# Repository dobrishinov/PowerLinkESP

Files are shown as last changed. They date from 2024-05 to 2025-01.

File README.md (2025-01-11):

# PowerLinkESP

PowerLinkESP is an advanced firmware designed to enhance Nice-Power bench power supplies with ESP8266 connectivity, providing advanced monitoring and control capabilities.

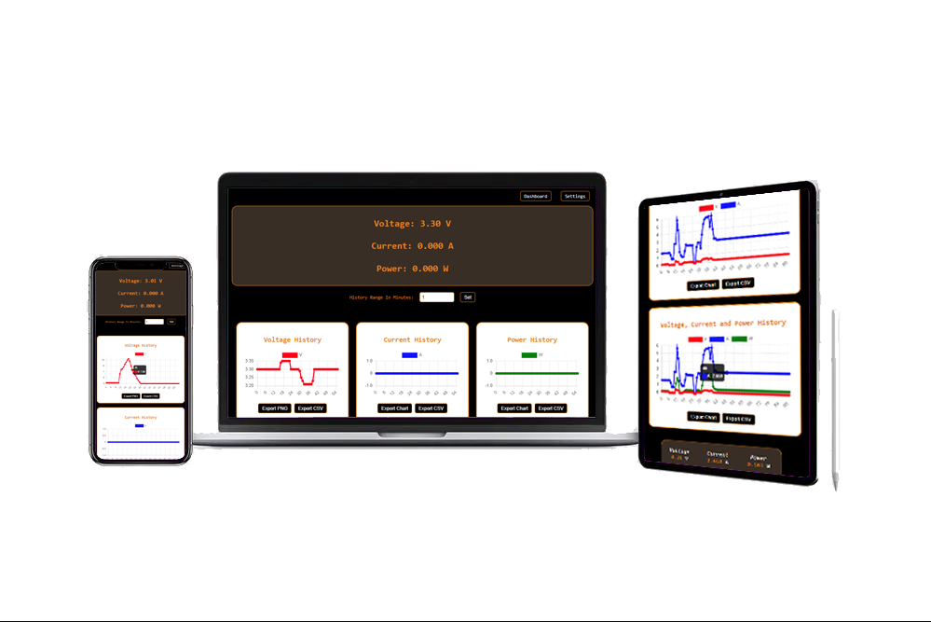
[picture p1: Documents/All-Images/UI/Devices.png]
Different Devices with the software

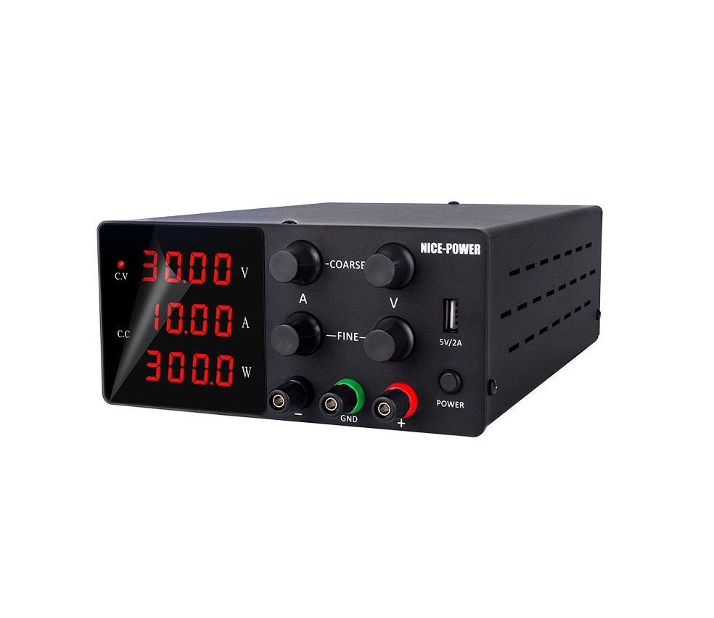
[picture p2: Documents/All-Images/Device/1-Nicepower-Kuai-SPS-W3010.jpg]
Nice-Power Bench Power Supply


## Overview

PowerLinkESP revolutionizes the interaction with Nice-Power bench power supplies by offering seamless integration via UART protocol. Designed with versatility and user-friendliness in mind, this firmware empowers users to monitor, control, and optimize their bench power supply experience through a sophisticated yet intuitive user interface.

## Features

### User Interface

- **Real-time Monitoring:** Dynamic gauges provide live updates on voltage, current, and power output.
- **Interactive Charts:** Dive deeper into your data with interactive charts for voltage, current, and power.
- **Export Functionality:** Export chart data history in PNG or CSV format for further analysis.
- **Persistent Information Bar:** Access live information about voltage, current, and power on a persistent bottom bar.
- **Customizable History Range:** Set the history range in minutes for chart data.
- **Customizable Update Frequency:** Set the update frequency in milliseconds for chart data.
- **Customizable Threshold Alarms:** Set custom threshold Alarm notifications with audible alerts when Voltage, Current, or Power reach specified values.

### Network Configuration

- **Dynamic & Static IP Support:** Choose between dynamic and static IP assignment.
- **WIFI AP or STA Mode:** Configure the ESP8266 in access point (AP) or station (STA) mode.
- **Automatic AP Mode:** Automatically switch to AP mode if the configured station (STA) network is unavailable.

### Communication & Connectivity

- **UART Communication:** Ensure reliable data transmission with Nice-Power bench power supplies.
- **Async Web Server:** Enjoy responsive and efficient communication with the user interface.
- **OTA (Over-The-Air) Updates:** Update firmware directly from the Arduino IDE.
- **EEPROM Configuration Store:** Store configuration settings in EEPROM memory for persistent operation.

## UI Interface

#### Big Screen - All Charts
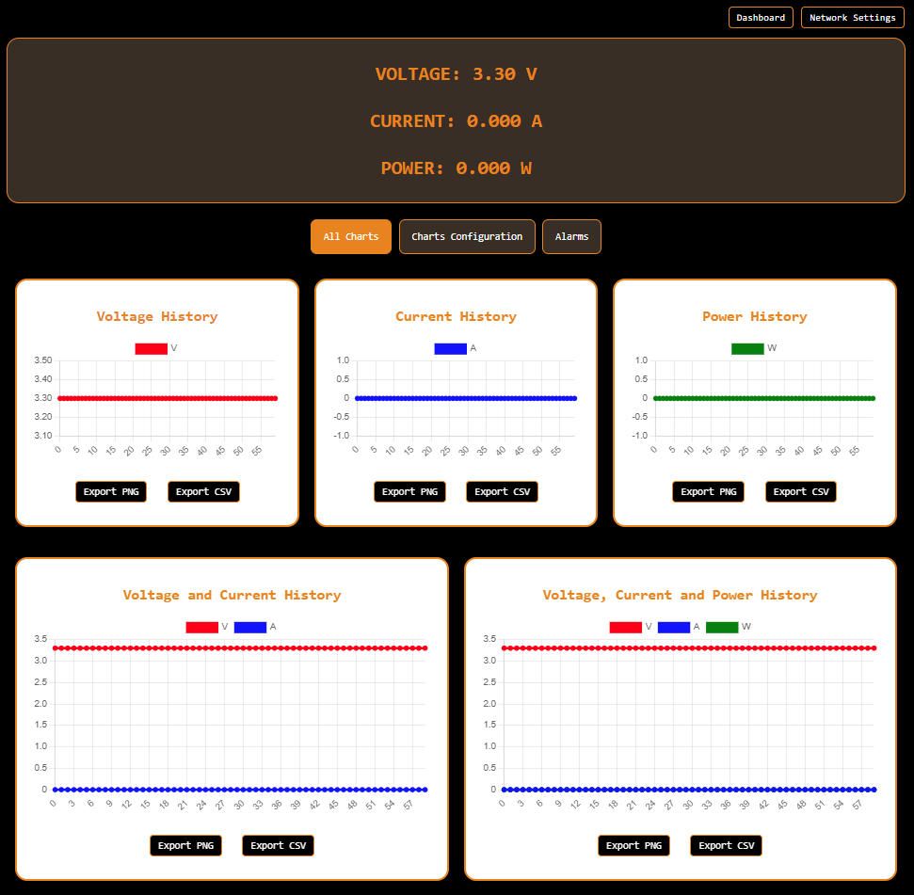
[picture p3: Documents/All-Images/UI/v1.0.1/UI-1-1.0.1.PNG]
Big Screen - All Charts


#### Big Screen - Charts Configuration
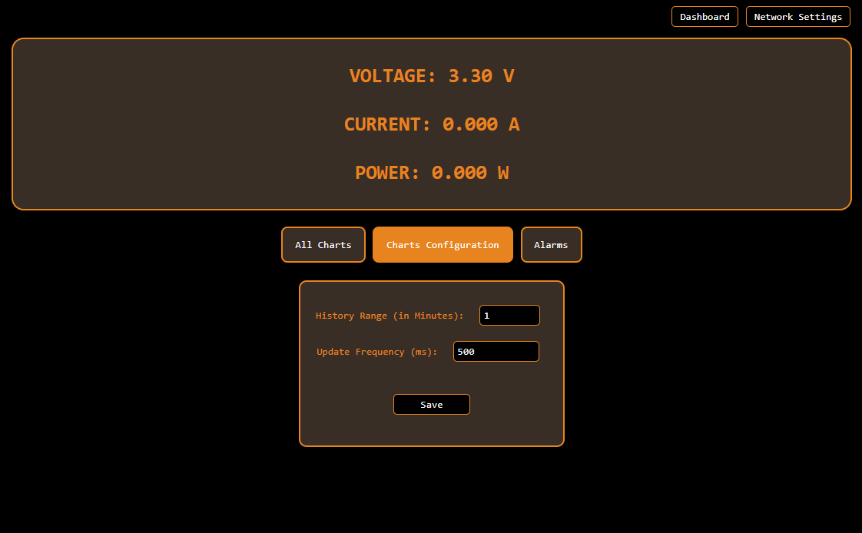
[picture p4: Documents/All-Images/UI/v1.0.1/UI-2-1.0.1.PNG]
Big Screen - Charts Configuration


#### Big Screen - Threshold Alarms
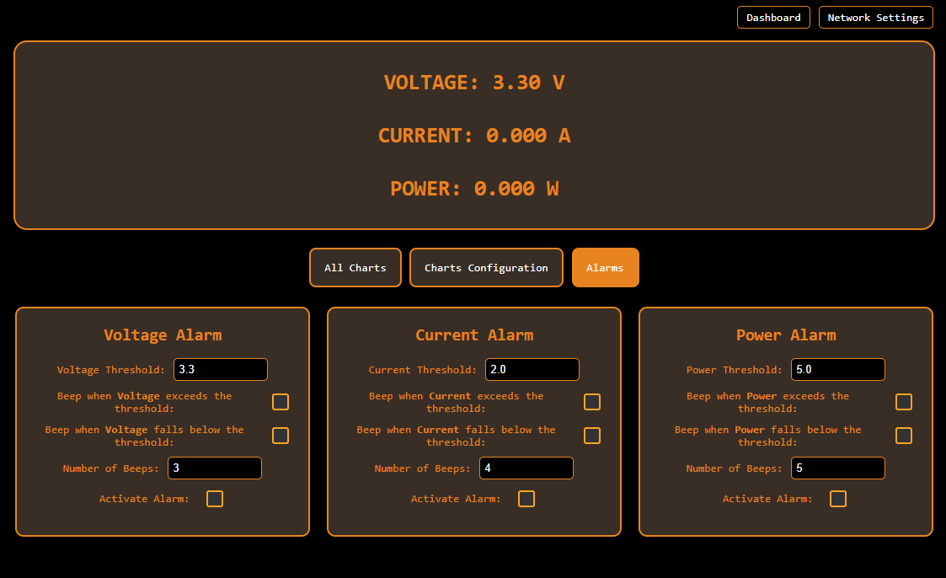
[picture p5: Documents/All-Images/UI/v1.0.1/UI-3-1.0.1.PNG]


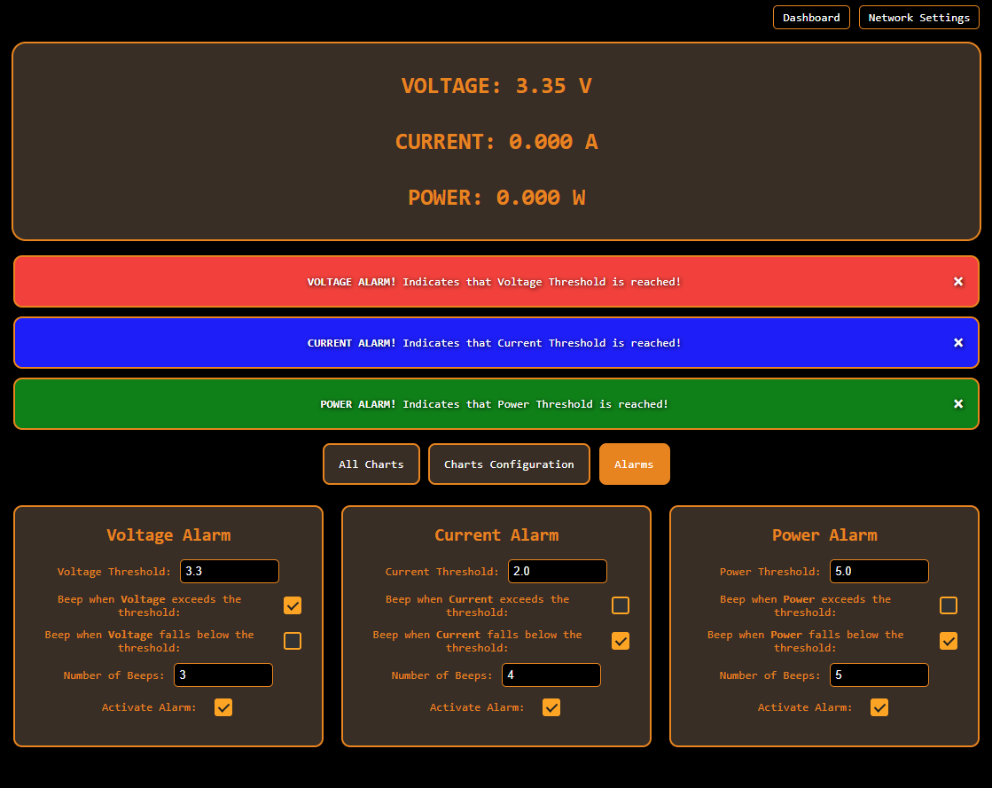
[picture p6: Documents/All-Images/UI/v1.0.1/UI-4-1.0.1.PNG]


#### Big Screen - Settings Page
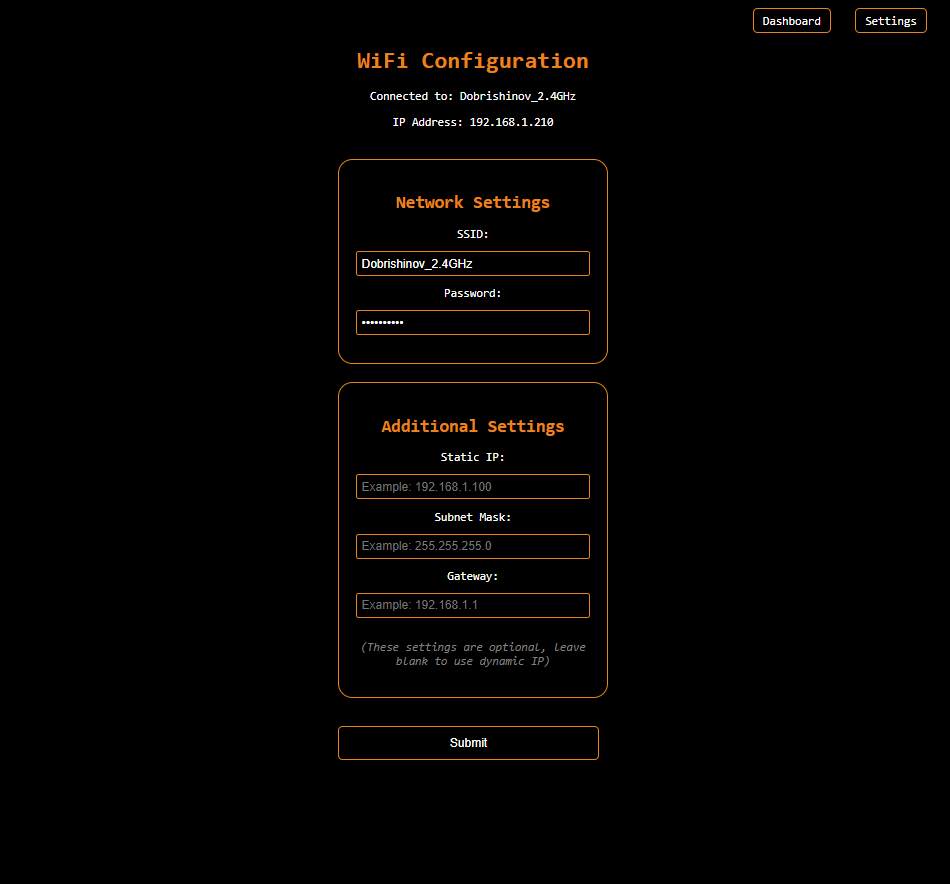
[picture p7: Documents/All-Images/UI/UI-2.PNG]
Nice-Power Bench Power


#### Mobile Screen - Dashboard
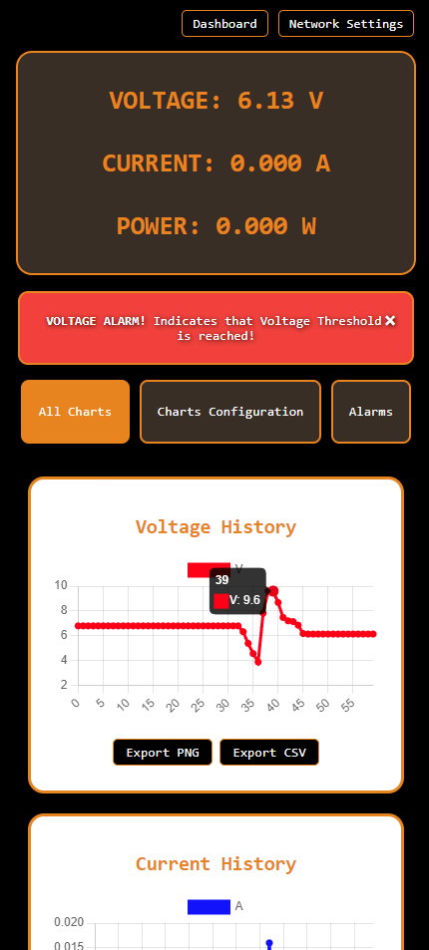
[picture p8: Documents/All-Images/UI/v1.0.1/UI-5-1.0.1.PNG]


When we scrolling the top display with values is hidden, but we have handy pinned display with the values at the bottom.

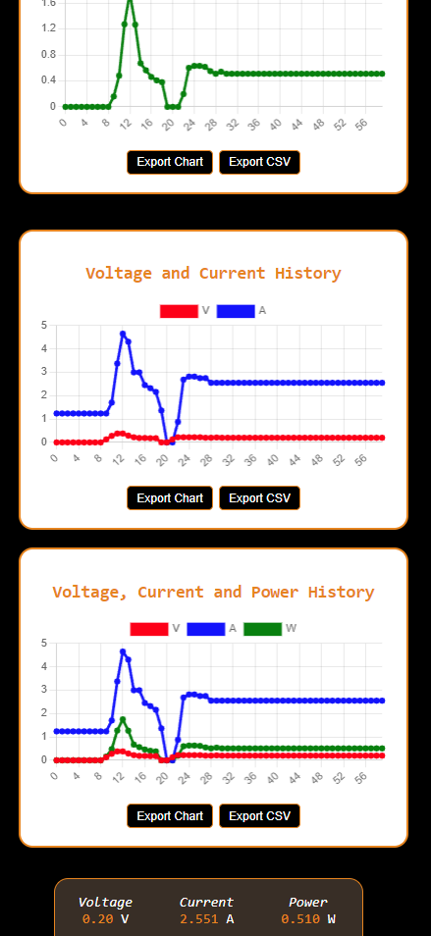
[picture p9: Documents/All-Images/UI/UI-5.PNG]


## Hardware Setup

**Wiring Schematic:**

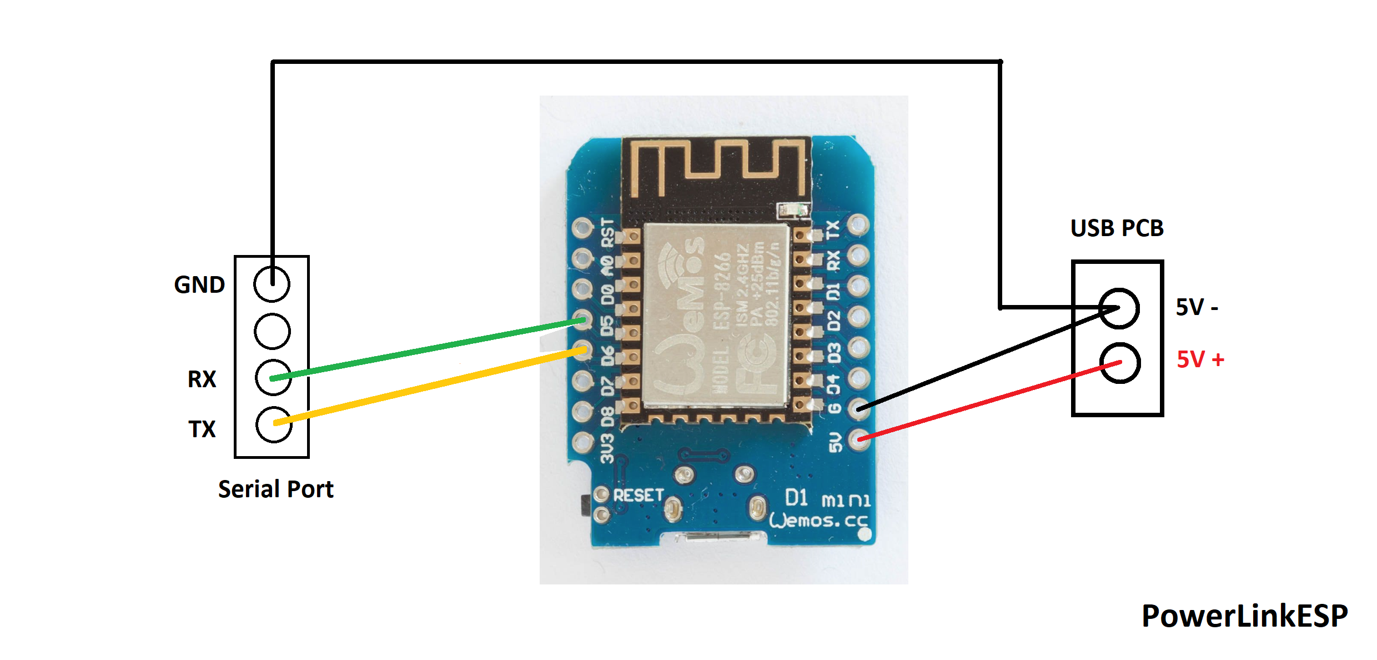
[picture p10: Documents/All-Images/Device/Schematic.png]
Simple Schematic


- Refer to the provided wiring schematic for proper connection between the Wemos D1 mini microcontroller and the Nice-Power bench power supply via UART.

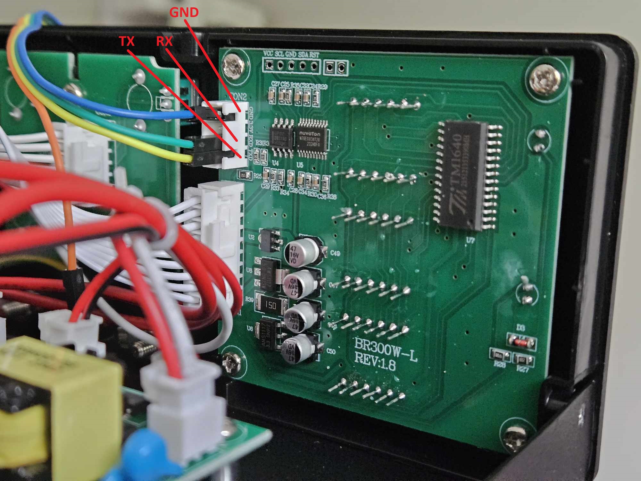
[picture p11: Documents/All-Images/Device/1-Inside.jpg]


- You need to connect Nice-Power supply UART Port to the WEMOS D1 Mini.
- RX from Nice-Power needs to be connected to the D5 pin on the WEMOS D1 Mini
- TX from Nice-Power needs to be connected to the D6 pin on the WEMOS D1 Mini
- We need to connect GND Pin to the WEMOS D1 Mini GND pin and also to the Nice-Power USB GND pin.

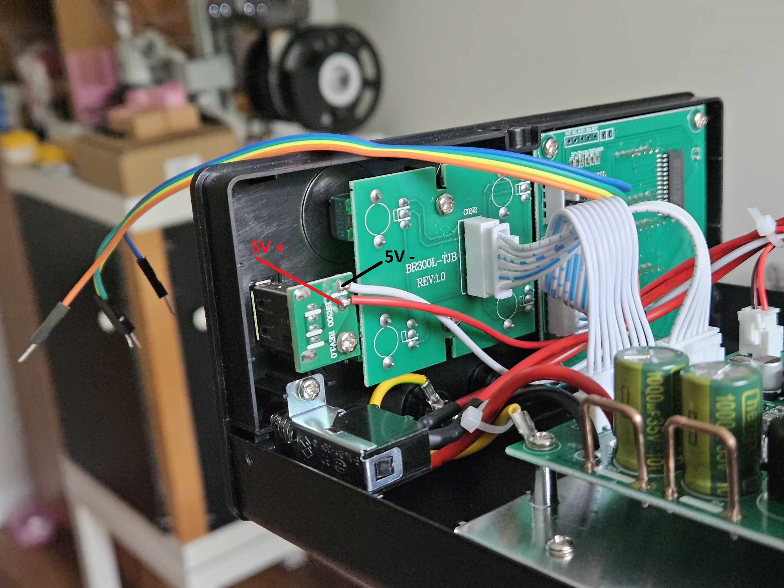
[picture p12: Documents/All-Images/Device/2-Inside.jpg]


- We need to power the WEMOS D1 Mini from the Nice-Power supply USB port.

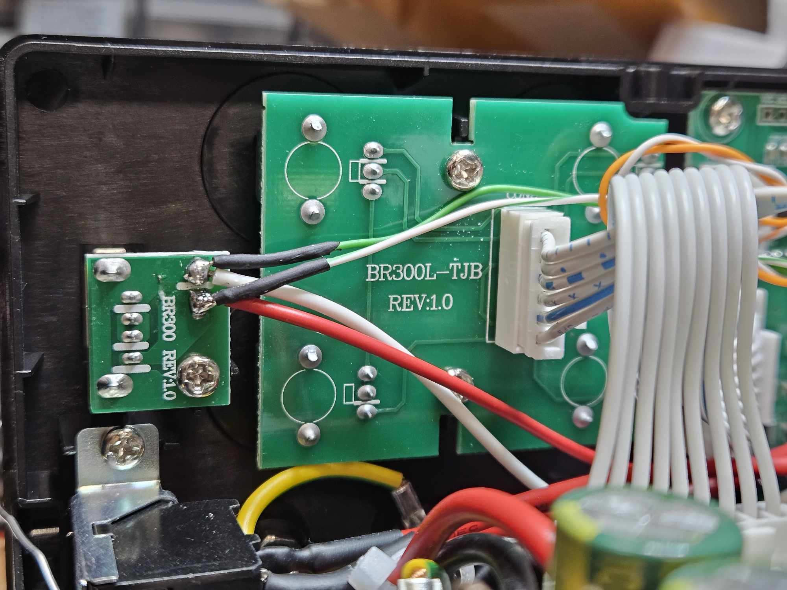
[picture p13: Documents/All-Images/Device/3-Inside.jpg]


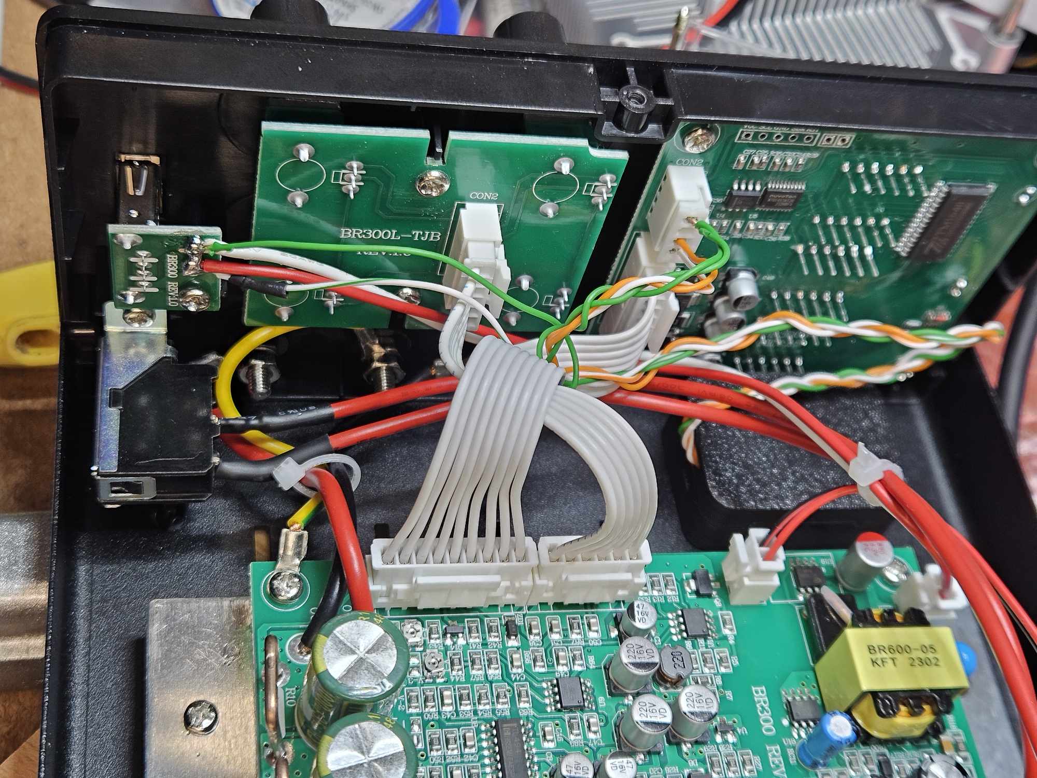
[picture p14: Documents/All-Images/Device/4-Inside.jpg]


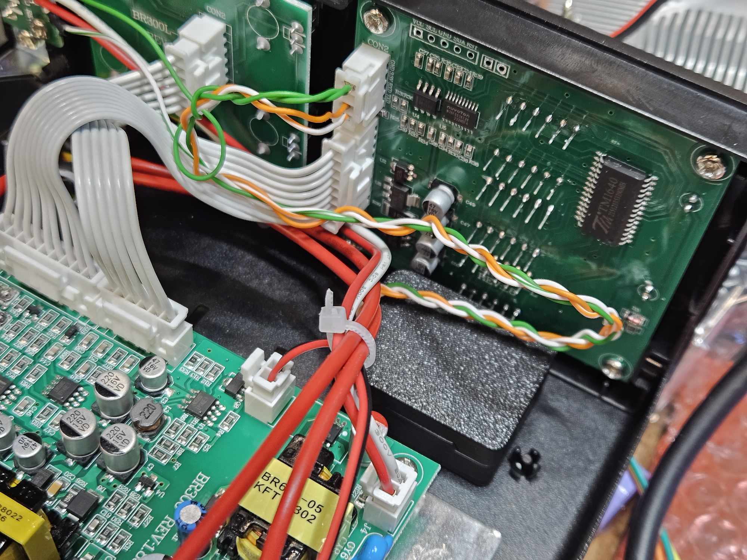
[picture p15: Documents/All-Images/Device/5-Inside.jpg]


**3D Printed Case for Wemos D1 mini:**

- I used this 3D printed case designed specifically for the Wemos D1 mini microcontroller - https://makerworld.com/en/models/20157
- You can find also the STL files in "3DModelCaseFiles" directory. 

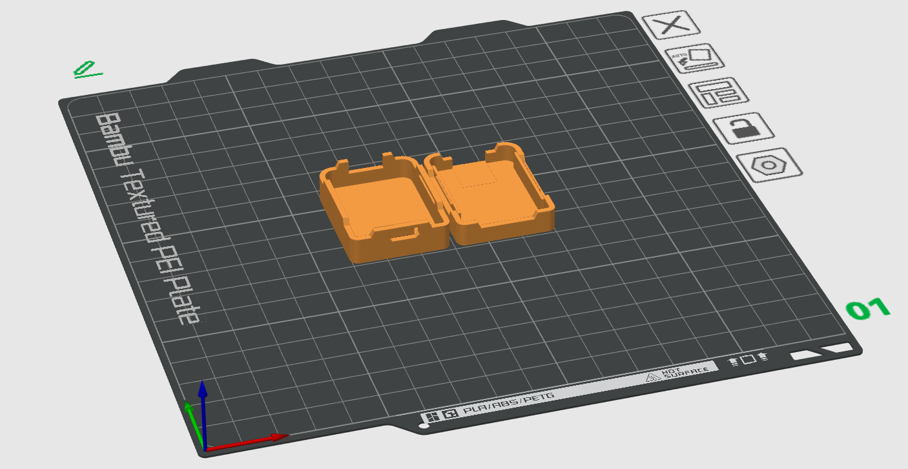
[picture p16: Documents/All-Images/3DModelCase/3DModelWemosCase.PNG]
3D Printed Case


## Installation

1. **Clone the Repository (Latest Version):**
   [git clone https://github.com/yourusername/powerlink-esp.git](https://github.com/dobrishinov/PowerLinkESP.git)
   
   **OR**

   **Get the Latest Stable Release:**
   - If you prefer a stable release, follow these steps:
      - Visit the repository’s releases page.
      - Look for the desired version (usually tagged as "Stable").
      - Download the release package associated with that version.
      - Extract the contents to your preferred location.

2. **Setup Arduino IDE:**
   - Download and Install Arduino IDE:
      - The project is build on Arduino version ***1.8.19***, you can try to build it with the latest version, but in case of a problem try with ***1.8.19***
      - Install the IDE by following the instructions for your operating system.

   - Install Required Libraries:

      - Open Arduino IDE.
      - Go to **Sketch > Include Library > Manage Libraries...**.
      - In the Library Manager, search for and install the following libraries:
         - **ESPAsyncTCP** (version ***1.2.2*** from Me-No-Dev)
         - **ESPAsyncWebServer** (version ***1.2.3*** from Me-No-Dev)
         - **TaskScheduler** (version ***3.7.0*** from Anatoli Arkhipenko)
         - ***The Libraries are also included in this repository***
   
   - Add ESP8266 Board to Arduino IDE:
      - Go to **File > Preferences**.
      - In the "Additional Board Manager URLs" field, add the following URL: 
      ```http://arduino.esp8266.com/stable/package_esp8266com_index.json```
      - Click **OK**
      - Go to **Tools > Board > Boards Manager**.
      - Search for **esp8266** and install **esp8266 by ESP8266 Community**.

3. **Upload Firmware:**
   - Open the Project:
      - Open the Arduino IDE.
      - Go to **File > Open** and navigate to the cloned repository folder. Open the .ino file within the repository.

   - Select the Board:
      - Go to **Tools > Board > ESP8266 Boards** and select **LOLIN(WeMos) D1 mini (clone)**.

   - Configure Board Settings:

      - Ensure the following settings under the Tools menu:
         - Board: ***LOLIN(WeMos) D1 mini (clone)***
         - Flash Size: ***4M (FS:2MB OTA:~1019KB)***
         - Upload Speed: ***921600***
   - Connect the Device:
      - Connect your LOLIN(WeMos) D1 mini (clone) mini to your computer via USB.

   - Upload the Firmware:
      - Click the Upload button (right arrow icon) in the Arduino IDE.
      - Wait for the IDE to compile and upload the firmware to your LOLIN(WeMos) D1 mini (clone) device.

   - Upload the Web Page Data files

      - Install **Arduino ESP8266 LittleFS Filesystem Uploader**
      - Open your Arduino directory and put the ***esp8266fs.jar*** which you can find 
      in the repository Arduino directory. The path should be something like this one:
      ```~Documents/Arduino/tools/ESP8266FS/tool/esp8266fs.jar```
      - If you have problems with this step please check the links below:
         - https://randomnerdtutorials.com/install-esp8266-nodemcu-littlefs-arduino/
         - https://github.com/earlephilhower/arduino-esp8266littlefs-plugin
      - Then make sure you have selected a board, port, and closed Serial Monitor.
      - Select **Tools > ESP8266 LittleFS Data Upload** menu item. This should start uploading the files into ESP8266 flash file system. When done, IDE status bar will display LittleFS Image Uploaded message. Might take a few minutes for large file system sizes.

4. **Additional Notes**

   - Make sure you have the correct COM port selected under **Tools > Port**.
   - If you encounter any issues during the upload process, ensure your device drivers are properly installed and try using a different USB cable.
   - The default WIFI password for the Access Point is ***12345678***. If you want to change it please edit the password for the AP in the code. The variable is ***fallbackPassword***.

## Usage

**Accessing the User Interface:**

There is two working modes:
   - Access Point Mode
      - On First boot the device is created Access Point with name: ***LabPowerSupply_[IdOfTheESP]***
      - The default WIFI password for the Access Point is ***12345678***. (If you want to change it please edit the password for the AP in the code. The variable is ***fallbackPassword***).
      - Open in the URL ***192.168.4.1*** and you can see the UI Interface.
      - Go to the Settings page and add your WIFI credentials if you want to use the device in your local network.

   - Station Mode
      - Connect the Wemos D1 mini to your local network and obtain its IP address.
      - Open a web browser and enter the IP address of the Wemos D1 mini to access the user interface.
      - Explore the intuitive user interface to monitor real-time data from the bench power supply.
      - Utilize interactive charts and export functionality to analyze historical data.
      - Customize network settings and configuration options as needed.
      - If the WIFI network is not reachable, the device will run automatically in Access Point Mode.

## To-Do / Wishlist

Below is a list of upcoming features and enhancements:

:heavy_check_mark: [Done] Added option to set the update frequency for the charts.

:heavy_check_mark: [Done] Added favicon with nice power icon.

:heavy_check_mark: [Done] Added Alarm threshold notifications with audible alerts when Voltage, Current, or Power reach specified values..

:hourglass_flowing_sand: Update README regularly.

:star: :rainbow: :star: Feel free to suggest new features or improvements by opening an issue or submitting a pull request. Your contributions are always welcome!

## Contributing

Contributions from the community is welcome! I'll be happy for further enhance the functionality and usability of PowerLinkESP. Whether you're a seasoned developer or a passionate enthusiast, your contributions are invaluable to shared success. 
In the Documents directory, you’ll find a useful document explaining how the serial port protocol works. This protocol may also be applicable to power supplies from other brands.
Feel free to explore the repository, open issues, submit pull requests, or engage in discussions to contribute to the ongoing development efforts.

## License

This project is licensed under the GPL-3.0 license - see the [LICENSE](LICENSE) file for details.

## Contact

For feedback, or collaboration opportunities, please contact [dobrishinov@gmail.com](mailto:dobrishinov@gmail.com)

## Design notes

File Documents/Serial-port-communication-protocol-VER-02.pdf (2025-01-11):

## Communication protocol of programmable regulated power supply

This series of instruments adopts RS232 or USB or RS485 transmission standard to communicate with the computer. The details are as follows:

Baud rate：1200，2400，4800，9600,19200 Default Value :9600
Start bit：1
Data bits：8
Check bit：none
Stop bit：1

Frame structure
Message sending should start with a pause interval of at least 3.5 characters; The whole message frame must be a continuous data transmission stream. If there is a pause time of more than 3.5 characters before the frame is completed, the receiving device will refresh the incomplete message and assume that the next byte is the address field of a new message. Similarly, if a new message starts with the previous message in less than 3.5 characters, the receiving device will consider it as the continuation of the previous message.

The standard structure of a frame of information is as follows：

Start | 1 | 2 | 3 | 4 | 5 | 6 | 7 | 8 | 9 | 10 | 11 | end
< | 0 | 2 | 0 | 0 | 4 | 5 | 8 | 0 | 0 | 0 | 0 | >

Start

bit

Address

bit

Function

bit

Data bits 1 | Data bits 2 | Device address

End
bit

Function
1. Set voltage
2. Read voltage
3.Set current
4.Read current

Read voltage return data format:<12012000000> return 12V
Read current return data format:<14009300000> < The first digit in the back represents the CV CC state, 1 is the CV state, C is the CC state, and the following value is the current value 9.3A
<12000000000> | The return voltage is 0 CV
<C4000000000> | The return current is 0 CC

ASCII sending<01012100001>indicates setting the power supply voltage of device address: 1 to 12.10V (RS4
Hexadecimal transmission 3C 30 31 30 31 32 31 30 30 30 30 31 3E

ASCII sending<01012100100>indicates setting the power supply voltage of device address: 100 to 12.10V (R
Hexadecimal transmission 3C 30 31 30 31 32 31 30 30 31 30 30 3E

(Note:<01012100001>Convert to ASCII and send)

The data format is fixed in length, and if there is not enough length, use 0 to fill in

PC terminal reading voltage
Example:<12004580000>
Indicates reading 4.58V voltage on the dial
Example:<12004580001>
Indicates the reading device address: 1. The voltage on the power dial is 4.58V

PC end reading current
Example:<14000183000>
Indicates reading 0.183A current on the dial
Example:<14000183001>
Indicates the reading device address: 1. The current on the power dial is 0.183A

PC connection (sent by PC)

<09100000000>
<01004580000>
<03006920000>

PC disconnected (PC sent to MCU) <09200000000>

PC query voltage and current
<04003300000> Query current MCU return <14000183000> <02012200000> Query voltage MCU return <12004580000>

PC set voltage
<01004580000> Set voltage MCU return<11OK0000000>

PC set current
<03006920000> Set current MCU return <13OK0000000>
PC startup power | <07000000000>
PC power off | <08000000000>

VER:02
2023.8.11

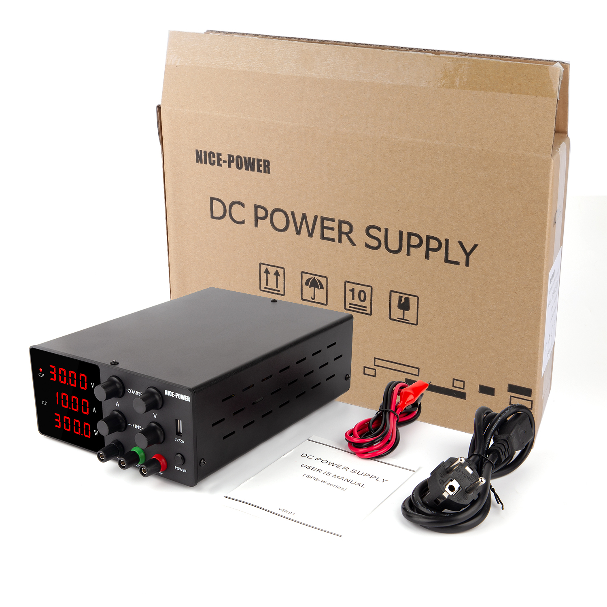
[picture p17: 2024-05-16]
Documents/All-Images/Device/8-Nicepower-Kuai-SPS-W3010.jpg

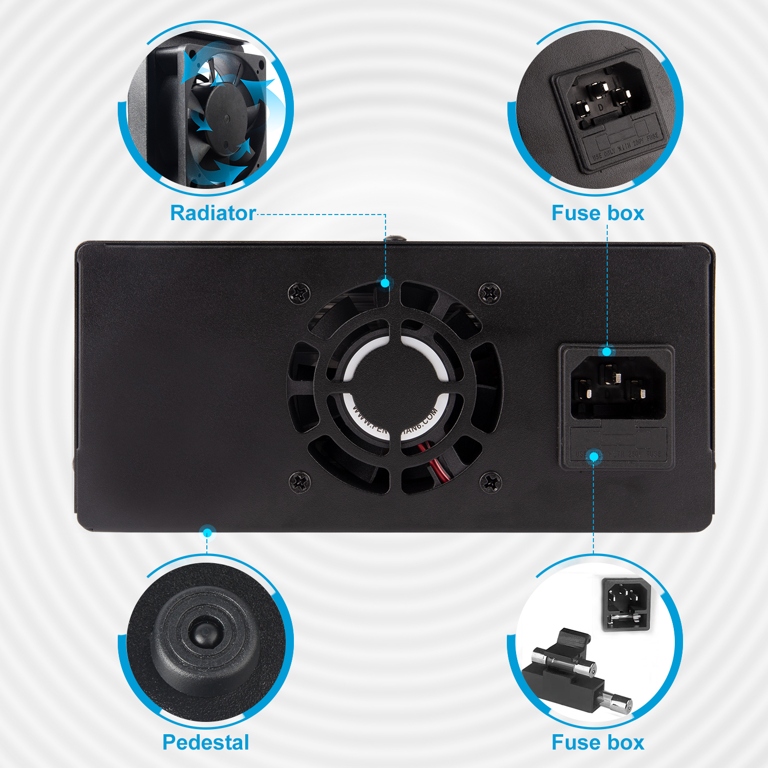
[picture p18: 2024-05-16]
Documents/All-Images/Device/3-Nicepower-Kuai-SPS-W3010.jpg

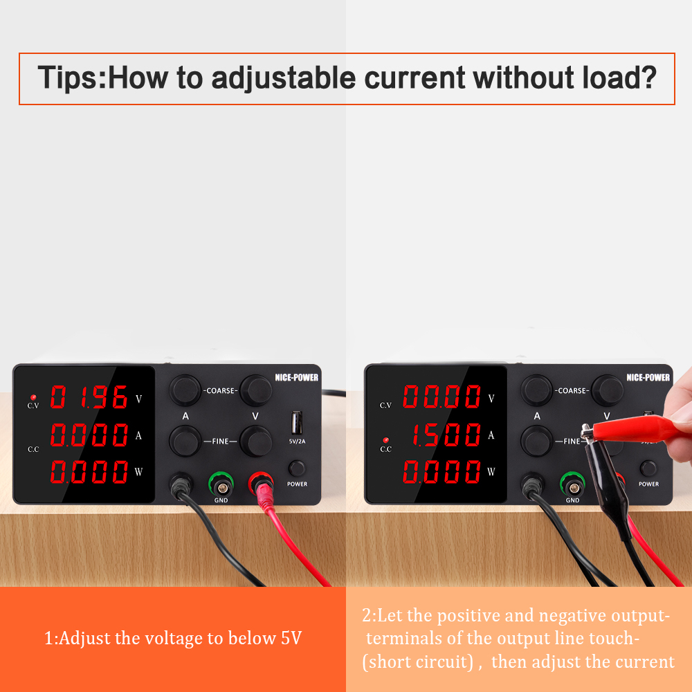
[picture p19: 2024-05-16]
Documents/All-Images/Device/7-Nicepower-Kuai-SPS-W3010.jpg

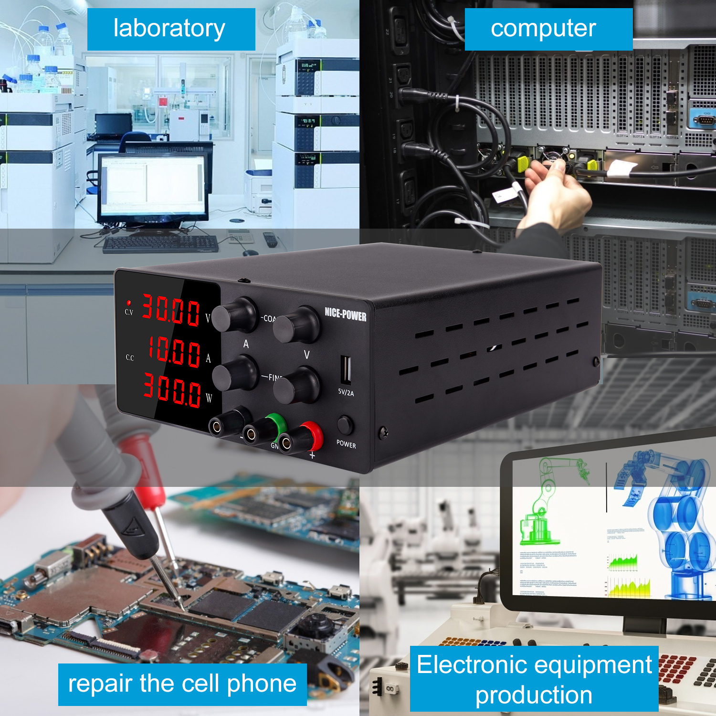
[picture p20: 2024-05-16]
Documents/All-Images/Device/5-Nicepower-Kuai-SPS-W3010.jpg

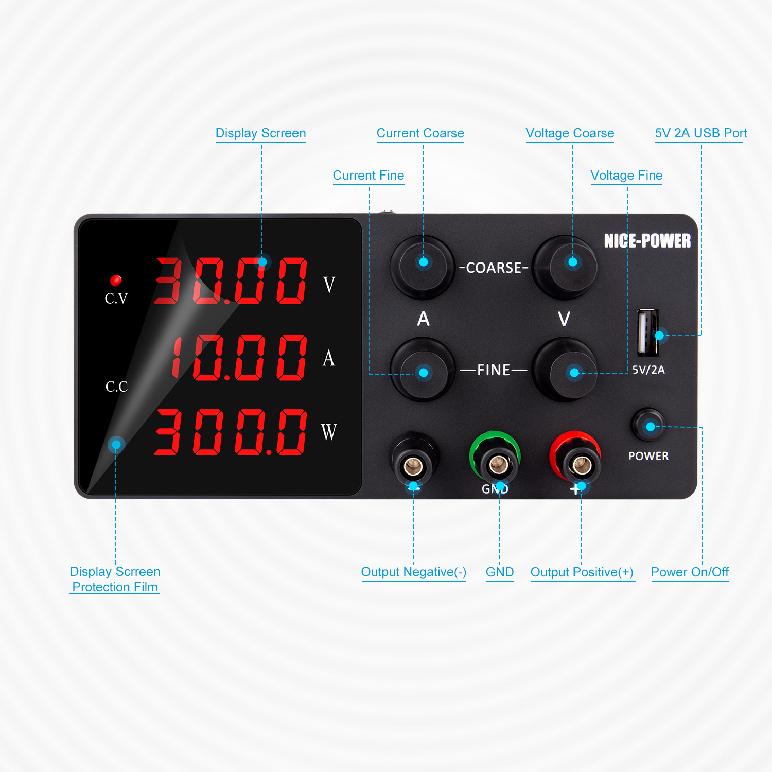
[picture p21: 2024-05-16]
Documents/All-Images/Device/2-Nicepower-Kuai-SPS-W3010.jpg

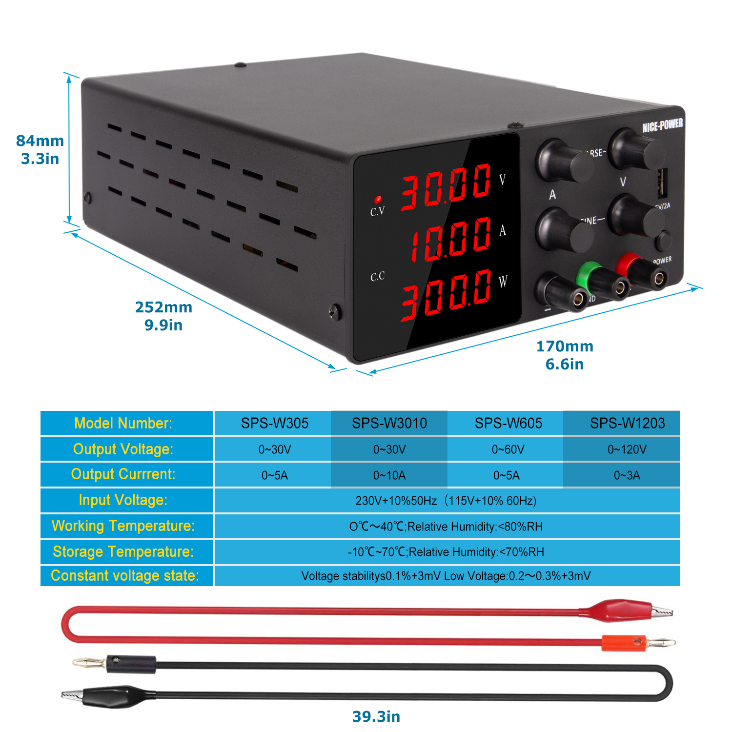
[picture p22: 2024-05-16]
Documents/All-Images/Device/4-Nicepower-Kuai-SPS-W3010-.jpg

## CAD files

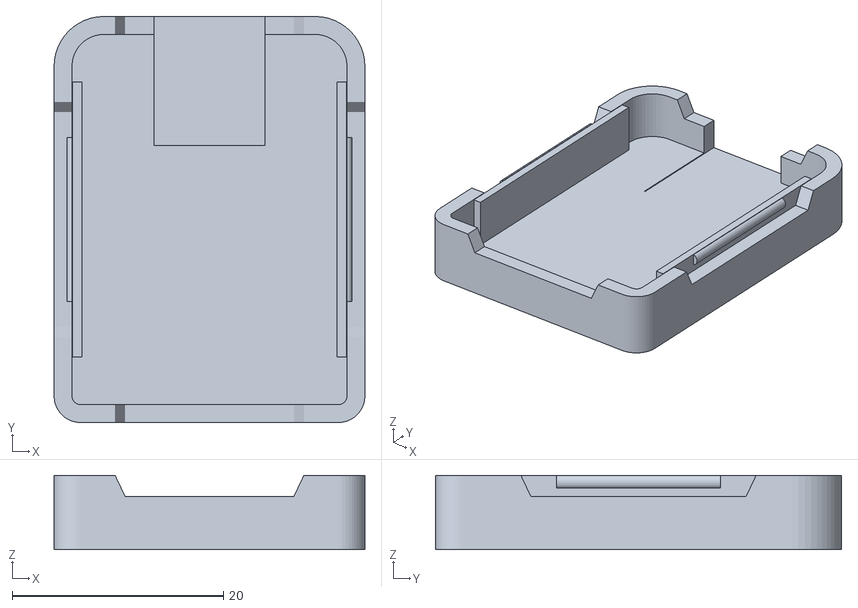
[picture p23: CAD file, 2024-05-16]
3DModelCaseFiles/wemos-case-top.stl
29.4 x 38.4 x 7.00

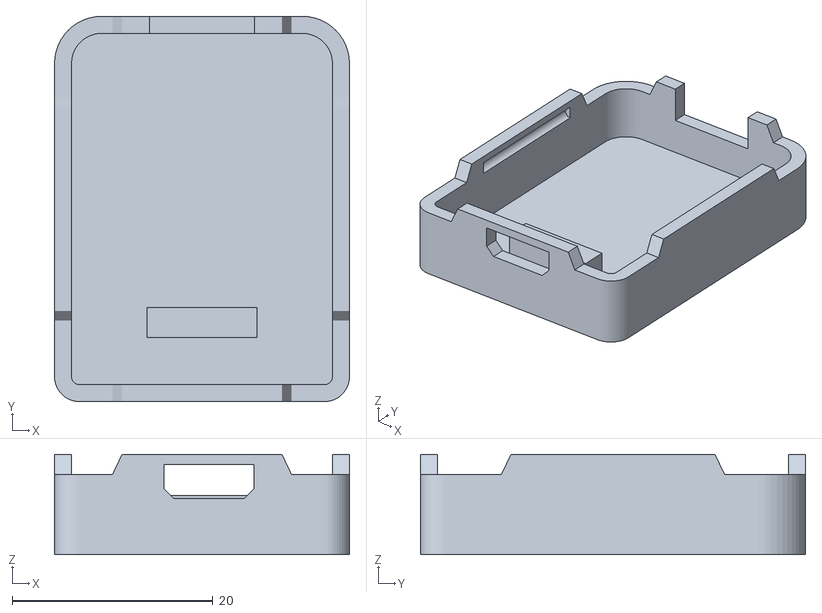
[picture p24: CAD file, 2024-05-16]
3DModelCaseFiles/wemos-case-bottom.stl
29.4 x 38.4 x 10.0

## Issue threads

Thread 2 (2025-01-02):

Expand to support dual power supply units

Felixrising, 2025-01-02:
Hi! Nice work!
I have this up and running on my own nice-power SPS310-2KD, this unit has two internal powersupplies that can be connected together in parallel, series or left as independent supplies. I have PowerLinkESP running on it's convenient serial header (that also prives the necessary 3v3 volts)!

PowerLinkESP is currently only pulling data from the left power supply bank.

Do you have a reference paper for the controller so I can expand on your project to support the dual power supplies or add more features? Where did you get the 12000000000 and 14000000000 voltage and current commands from? I was going to try just throwing more values at it to see what it returns... but was hoping you had a better resource :)

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

dobrishinov, 2025-01-11:
Hi! I'm happy to help.

Regarding the SPS3010-2KD power supply, it seems to be a great device. Nice-Power devices are also branded under the name KUAIQU. You can find their official support page here: [Nice-Power Support](https://nice-power.com.cn/Download).

From their download section, you can check out these archives:

2024-07-19
[多国语言MODBUS通信协议.rar](https://nice-power.com.cn/filedownload/128305)
File size: ~502 KB

2024-05-13
[DC Power Supply Software.zip](https://nice-power.com.cn/filedownload/123923)
File size: ~709 MB

You might not need to dive into the ModBus documentation, as the power supplies we are working with communicate over a serial port. The ModBus protocol documentation might be for other devices, as our PSUs (without a rotary encoder) are designed to only send information via the serial bus.

For more details, you can explore the DC Power Supply Software.zip, which includes a .doc file. Additionally, I’ve attached a PDF with the protocol instructions for convenience:

[Communication protocol-VER-02.pdf](https://github.com/user-attachments/files/18386471/Communication.protocol-VER-02.pdf)

You might also need to identify the specific bits for addressing the second hardware supply within your PSU. Try experimenting by modifying some bits to figure out the correct addresses for controlling voltage and current. This might take some trial and error but should help you pinpoint the proper configuration.

Just to note there’s another version of the PSUs with a rotary encoder and enhanced controls. That version allows for sending parameters (like voltage and current) directly via the serial bus. However, the version I have only supports monitoring capabilities over serial.

I hope this information helps! Feel free to update me on your progress. 😊

dobrishinov, 2025-01-23:
Unfortunately, I don't have the device in question at the moment and am not planning to implement it right now as I lack the necessary hardware for testing. However, I encourage you to experiment with the protocol on your own.

Felixrising, 2025-01-24:
Yeah, I got some copies of those docos from Nice-Power. Some chinglish issues in there and inconsistencies with my own testing - I emailed support again to clarify on this . I have run some checks with the help of this
 tool [ https://github.com/Felixrising/wireless-serial-gateway ] have the following functions documented and tested.

| Command            | Function              | PSU   | Typical Response   | Response Breakdown                                                      | Theoretical Range      | Observed Range       | Notes                                                                                                                 |
|--------------------|-----------------------|-------|---------------------|--------------------------------------------------------------------------|------------------------|----------------------|-----------------------------------------------------------------------------------------------------------------------|
| <11000000000>      | Set Voltage           | PSU1  | <11OK0000000>       | < + 1 (PSU1) + 1 (Set Voltage) + OK + 000000 (Data Field) + 000 (Addr) + > | Fixed acknowledgment   | N/A                  | Acknowledges successful voltage setting for PSU1                                                                     |
| <12000000000>      | Poll Voltage          | PSU1  | <12000378000>       | < + 1 (State: CV/CC) + 2 (Poll Voltage) + 003 (Int V) + 780 (Frac V) + 000 + > | 0.000 V to 999.999 V    | 0.000 V to 31.000 V   | '1' = CV mode, 'C' = CC mode                                                                                         |
| <13000000000>      | Set Current           | PSU1  | <13OK0000000>       | < + 1 (PSU1) + 3 (Set Current) + OK + 000000 (Data Field) + 000 (Addr) + > | Fixed acknowledgment   | N/A                  | Acknowledges successful current setting for PSU1                                                                     |
| <14000000000>      | Poll Current          | PSU1  | <14109300000>       | < + 1 (State: CV/CC) + 4 (Poll Current) + 093 (Int A) + 000 (Frac A) + 000 + > | 0.000 A to 999.999 A    | 0.000 A to 10.100 A   | '1' = CV mode, 'C' = CC mode                                                                                         |
| <18000000000>      | Turn OFF              | PSU1  | <18OK0000000>       | < + 1 (PSU1) + 8 (Turn OFF) + OK + 000000 (Data Field) + 000 (Addr) + > | Fixed acknowledgment   | N/A                  | Turns PSU1 off; uses function code '8'                                                                                 |
| <19000000000>      | Turn ON               | PSU1  | <19OK0000000>       | < + 1 (PSU1) + 9 (Turn ON) + OK + 000000 (Data Field) + 000 (Addr) + > | Fixed acknowledgment   | N/A                  | Turns PSU1 on; uses function code '9'                                                                                  |
| <21000000000>      | Set Voltage           | PSU2  | <21OK0000000>       | < + 2 (PSU2) + 1 (Set Voltage) + OK + 000000 (Data Field) + 000 (Addr) + > | Fixed acknowledgment   | N/A                  | Acknowledges successful voltage setting for PSU2                                                                     |
| <22000000000>      | Poll Voltage          | PSU2  | <22000378000>       | < + 2 (State: CV/CC) + 2 (Poll Voltage) + 003 (Int V) + 780 (Frac V) + 000 + > | 0.000 V to 999.999 V    | 0.000 V to 31.000 V   | '1' = CV mode, 'C' = CC mode                                                                                         |
| <23000000000>      | Set Current           | PSU2  | <23OK0000000>       | < + 2 (PSU2) + 3 (Set Current) + OK + 000000 (Data Field) + 000 (Addr) + > | Fixed acknowledgment   | N/A                  | Acknowledges successful current setting for PSU2                                                                     |
| <24000000000>      | Poll Current          | PSU2  | <24109300000>       | < + 2 (State: CV/CC) + 4 (Poll Current) + 093 (Int A) + 000 (Frac A) + 000 + > | 0.000 A to 999.999 A    | 0.000 A to 10.100 A   | '1' = CV mode, 'C' = CC mode                                                                                         |
| <27000000000>      | Turn ON               | PSU2  | <27OK0000000>       | < + 2 (PSU2) + 7 (Turn ON) + OK + 000000 (Data Field) + 000 (Addr) + > | Fixed acknowledgment   | N/A                  | Turns PSU2 on; uses different function code '7' compared to PSU1's '9'                                                  |
| <28000000000>      | Turn OFF              | PSU2  | <28OK0000000>       | < + 2 (PSU2) + 8 (Turn OFF) + OK + 000000 (Data Field) + 000 (Addr) + > | Fixed acknowledgment   | N/A                  | Turns PSU2 off; uses function code '8' which differs from PSU1's function codes for on/off                            |
| <26V5.000000>      | Return Version Info   | Both   | <26V5.000000>       | <26V5.000000>                                                            | N/A                    | N/A                  | Provides firmware or protocol version information. May be auto-sent or in response to a specific command.              |
| <29OK0000000>      | Confirmation Response | Both   | <29OK0000000>       | <29OK0000000>                                                              | N/A                    | N/A                  | General acknowledgment for certain commands. Possibly related to slave mode or synchronization status.                |

Closed 2025-01-23.

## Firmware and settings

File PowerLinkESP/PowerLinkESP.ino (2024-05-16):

#include <ESP8266WiFi.h>
#include <EEPROM.h>
#include <LittleFS.h>
#include <ESPAsyncTCP.h>
#include <ESPAsyncWebServer.h>
#include <SoftwareSerial.h>
#include <TaskScheduler.h>
#include <ArduinoOTA.h>

// EEPROM addresses for SSID, password, IP, subnet mask, and gateway
#define SSID_ADDR 0
#define PASS_ADDR 32
#define IP_ADDR 64
#define SUBNET_ADDR 96
#define GATEWAY_ADDR 128

// Fallback SSID and password
String uniqueDeviceName = "LabPowerSupply_" + String(ESP.getChipId());
const char* fallbackSSID = uniqueDeviceName.c_str();
const char* fallbackPassword = "12345678"; //Change this default password if you want to have different password for the AP

const int RXPin = D6; // Wemos D1 Mini RX pin
const int TXPin = D5; // Wemos D1 Mini TX pin

SoftwareSerial virtualSerial(RXPin, TXPin);
Scheduler runner;
AsyncWebServer server(80);

String voltageCommand = "<12000000000>"; // Default voltage command
String currentCommand = "<14000000000>"; // Default current command

float voltageValue = 0.0;
float currentValue = 0.0;
float powerValue = 0.0;

void sendVoltageCommand() {
  String response = sendCommandAndWait(voltageCommand);
  if (!response.isEmpty()) {
    handleVoltageCommand(response);
  }
}

void sendCurrentCommand() {
  String response = sendCommandAndWait(currentCommand);
  if (!response.isEmpty()) {
    handleCurrentCommand(response);
  }
}

String sendCommandAndWait(String command) {
  virtualSerial.print(command);
  // Wait for response
  unsigned long startTime = millis();
  while (!virtualSerial.available()) {
    if (millis() - startTime > 2000) { // Timeout after 2 seconds
      Serial.println("Timeout occurred while waiting for response from Power supply.");
      return "";
    }
  }
  // Read response
  String response = virtualSerial.readStringUntil('>');
  return response;
}

void handleVoltageCommand(String response) {
  // Extract data bits from the response
  int voltage = response.substring(4, 9).toInt();
  // Calculate voltage value (assuming data bits are in the format provided)
  voltageValue = voltage / 1000.0;
  // Calculate power
  powerValue = voltageValue * currentValue;
}

void handleCurrentCommand(String response) {
  // Extract data bits from the response
  int current = response.substring(4, 9).toInt();
  // Calculate current value (assuming data bits are in the format provided)
  currentValue = current / 1000.0;
  // Calculate power
  powerValue = voltageValue * currentValue;
}

void handleData(AsyncWebServerRequest *request) {
  String data = "{\"voltage\": " + String(voltageValue, 3) + ", \"current\": " + String(currentValue, 3) + ", \"power\": " + String(powerValue, 3) + "}";
  request->send(200, "application/json", data);
}

Task taskSendVoltage(500, TASK_FOREVER, &sendVoltageCommand);
Task taskSendCurrent(600, TASK_FOREVER, &sendCurrentCommand);

void setup() {
  // Initialize Serial Monitor
  Serial.begin(9600);
  // Initialize SoftwareSerial
  virtualSerial.begin(9600);
  // Initialize EEPROM
  EEPROM.begin(512);

  // Initialize LittleFS
  if (!LittleFS.begin()) {
    Serial.println("Failed to mount LittleFS");
    return;
  }

  // Connect to WiFi using stored credentials or fallback
  connectWiFi();
  
  // Initialize tasks
  runner.init();
  runner.addTask(taskSendVoltage);
  runner.addTask(taskSendCurrent);
  
  // Enable tasks
  taskSendVoltage.enable();
  taskSendCurrent.enable();

  // Check if stored IP, subnet mask, or gateway in EEPROM are missing
  String storedIP = readStringFromEEPROM(IP_ADDR);
  String storedSubnetMask = readStringFromEEPROM(SUBNET_ADDR);
  String storedGateway = readStringFromEEPROM(GATEWAY_ADDR);

  if (storedIP.isEmpty() || storedSubnetMask.isEmpty() || storedGateway.isEmpty()) {
    Serial.println("Stored network configuration missing or incomplete. Using dynamic IP.");
    WiFi.config(0U, 0U, 0U); // Clear existing static IP configuration
  } else {
    // Configure static IP from EEPROM
    IPAddress ip, mask, gw;
    ip.fromString(storedIP);
    mask.fromString(storedSubnetMask);
    gw.fromString(storedGateway);
    WiFi.config(ip, gw, mask);
  }

  server.on("/", HTTP_GET, [](AsyncWebServerRequest *request) {
    request->send(LittleFS, "/index.html", "text/html");
  });
  server.on("/data", HTTP_GET, [](AsyncWebServerRequest *request) {
    handleData(request);
  });
  server.on("/config", HTTP_GET, [](AsyncWebServerRequest *request) {
    handleConfigPage(request);
  });
  server.on("/setconfig", HTTP_POST, [](AsyncWebServerRequest *request) {
    handleSetConfig(request);
  });
  server.on("/chart.js", HTTP_GET, [](AsyncWebServerRequest *request) {
    if (LittleFS.exists("/chart.js")) {
      request->send(LittleFS, "/chart.js", "application/javascript");
    } else {
      request->send(404, "text/plain", "File Not Found");
    }
  });
  server.begin();
  Serial.println("HTTP server started");
  
  // Port defaults to 8266
  // ArduinoOTA.setPort(8266);

  // Hostname defaults to esp8266-[ChipID]
  // ArduinoOTA.setHostname("myesp8266");

  // No authentication by default
  // ArduinoOTA.setPassword((const char *)"123");
  
  ArduinoOTA.onStart([]() {
    Serial.println("Start");
  });
  ArduinoOTA.onEnd([]() {
    Serial.println("\nEnd");
  });
  ArduinoOTA.onProgress([](unsigned int progress, unsigned int total) {
    Serial.printf("Progress: %u%%\r", (progress / (total / 100)));
  });
  ArduinoOTA.onError([](ota_error_t error) {
    Serial.printf("Error[%u]: ", error);
    if (error == OTA_AUTH_ERROR) Serial.println("Auth Failed");
    else if (error == OTA_BEGIN_ERROR) Serial.println("Begin Failed");
    else if (error == OTA_CONNECT_ERROR) Serial.println("Connect Failed");
    else if (error == OTA_RECEIVE_ERROR) Serial.println("Receive Failed");
    else if (error == OTA_END_ERROR) Serial.println("End Failed");
  });
  ArduinoOTA.begin();

  if (WiFi.getMode() == WIFI_STA && WiFi.status() == WL_CONNECTED) {
    // Print STA IP address
    Serial.println("IP Address: " + WiFi.localIP().toString());
  } else {
    // Print AP IP address
    Serial.println("IP Address: " + WiFi.softAPIP().toString());
  }
}

void loop() {
  runner.execute();
  ArduinoOTA.handle();
}

void connectWiFi() {
  String ssid = readStringFromEEPROM(SSID_ADDR);
  String password = readStringFromEEPROM(PASS_ADDR);

  // Attempt to connect to stored WiFi network
  if (ssid.length() > 0 && password.length() > 0) {
    Serial.println("Connecting to stored WiFi...");
    WiFi.hostname(uniqueDeviceName.c_str());
    WiFi.begin(ssid.c_str(), password.c_str());
  } else {
    Serial.println("Connecting to fallback WiFi...");
    WiFi.mode(WIFI_AP);
    WiFi.softAP(fallbackSSID, fallbackPassword);
  }

  // Wait for connection to be established
  int attempts = 0;
  while (WiFi.status() != WL_CONNECTED && attempts < 20) {
    delay(500);
    Serial.print(".");
    attempts++;
  }

  // If connection failed, start the access point
  if (WiFi.status() != WL_CONNECTED) {
    Serial.println("\nConnection failed. Starting AP...");
    WiFi.mode(WIFI_AP);
    WiFi.softAP(fallbackSSID, fallbackPassword);
  } else {
    Serial.println("\nConnected to WiFi!");
  }
}

void handleConfigPage(AsyncWebServerRequest *request) {
  String connectedSSID = "";
  String connectedPass = "";
  String ipAddress = "";

  // Check if device is in STA mode and connected to WiFi
  if (WiFi.getMode() == WIFI_STA && WiFi.status() == WL_CONNECTED) {
    connectedSSID = WiFi.SSID();
    connectedPass = WiFi.psk();
    ipAddress = WiFi.localIP().toString();
  } else {
    ipAddress = WiFi.softAPIP().toString();
  }
  // Load HTML file from LittleFS
  File htmlFile = LittleFS.open("/config_page.html", "r");
  if (htmlFile) {
    String page = htmlFile.readString();
    htmlFile.close();

    // Replace placeholders in HTML template with actual values
    page.replace("$CONNECTED_SSID$", connectedSSID);
    page.replace("$CONNECTED_PASS$", connectedPass);
    page.replace("$IP_ADDRESS$", ipAddress);

    request->send(200, "text/html", page);
  } else {
    request->send(500, "text/plain", "Failed to load configuration page.");
  }
}

void handleSetConfig(AsyncWebServerRequest *request) {
  String ssid = request->arg("ssid");
  String password = request->arg("password");
  String staticIP = request->arg("static_ip");
  String subnetMask = request->arg("subnet_mask");
  String gateway = request->arg("gateway");
  // Store SSID and password in EEPROM
  writeStringToEEPROM(SSID_ADDR, ssid);
  writeStringToEEPROM(PASS_ADDR, password);
  EEPROM.commit();

  // Check if static IP settings are provided
  if (!staticIP.isEmpty() && !subnetMask.isEmpty() && !gateway.isEmpty()) {
    // Store static IP configuration in EEPROM
    writeStringToEEPROM(IP_ADDR, staticIP);
    writeStringToEEPROM(SUBNET_ADDR, subnetMask);
    writeStringToEEPROM(GATEWAY_ADDR, gateway);
    EEPROM.commit();
    ESP.reset();
    // Set static IP configuration
//    IPAddress ip, mask, gw;
//    ip.fromString(staticIP);
//    mask.fromString(subnetMask);
//    gw.fromString(gateway);
//    WiFi.config(ip, gw, mask);
  } else {
    // Erase static IP configuration from EEPROM
    for (int i = IP_ADDR; i < GATEWAY_ADDR + 32; ++i) {
      EEPROM.write(i, 0);
    }
    EEPROM.commit();

    // Clear existing static IP configuration
    WiFi.config(0U, 0U, 0U);
    ESP.reset();
  }

  // Attempt to connect to the new WiFi network
  connectWiFi();

  // Send response to client
  if (WiFi.status() == WL_CONNECTED) {
    Serial.println("\nConnected to WiFi!");
    request->send(200, "text/plain", "Configuration saved and connected to WiFi.");
  } else {
    Serial.println("\nConnection to new WiFi failed!");
    request->send(200, "text/plain", "Configuration failed. Unable to connect to WiFi.");
  }
}

String readStringFromEEPROM(int addr) {
  String value = "";
  char c;
  for (int i = addr; i < addr + 32; ++i) {
    c = EEPROM.read(i);
    if (c == 0) break;
    value += c;
  }
  Serial.println("EEPROM Read String: " + value); // Print the read value
  return value;
}

void writeStringToEEPROM(int addr, String value) {
  int len = value.length();
  for (int i = 0; i < len; ++i) {
    EEPROM.write(addr + i, value[i]);
  }
  EEPROM.write(addr + len, 0); // Null-terminate the string
}

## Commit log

2024-05-16 Changed Device image
2024-05-16 Added images from inside of the device, added also Schematic
    [wemos-case-bottom.stl, wemos-case-top.stl]
2024-05-17 Added Arduino Libraries and tool, Changes in the README
